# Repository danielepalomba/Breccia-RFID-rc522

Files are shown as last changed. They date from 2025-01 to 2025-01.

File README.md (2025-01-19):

# Breccia-RFID-rc522

## Required Components
- Arduino board
- rc522 RFID module
- 1 or + MIFARE 1K Keys
- Relay module
- Active buzzer

*If you do not use a relay module, take care to include a diode and transistor in your circuit to prevent eddy currents from damaging the arduino board. In case you use a relay on a pre-fabricated board, then you will have no prob .*

## Connection diagram 

| RIFD | Arduino |
| ---- |---|
| SDA  | D10 |
| SCK  | D13 |
| MOSI | D11 |
| MISO | D12 |
| GND  | GND |
| RST  | D9 |
| VCC  | 3.3V |

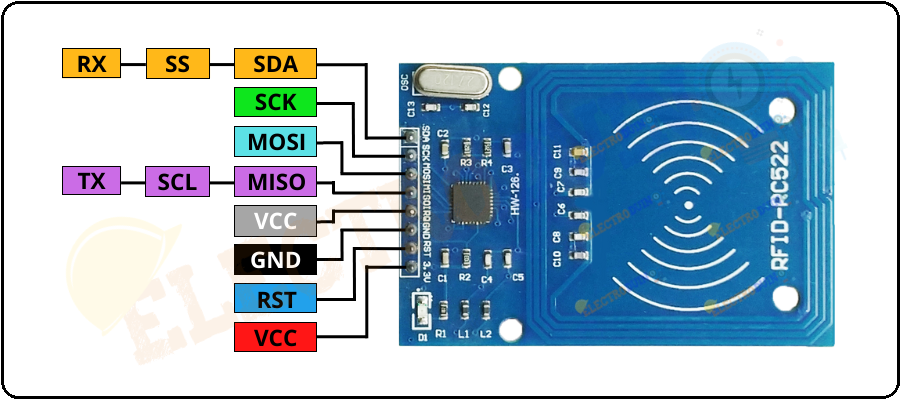
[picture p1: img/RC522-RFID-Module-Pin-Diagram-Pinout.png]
Connection diagram


| Relay board | Arduino |
| --- |:--- |
| Signal | D4 |
| VCC | 5V |
| GND | GND |

| A. Buzzer | Arduino |
|:--- | --- |
| VCC (+) | D3 |
| GND | GND |

The rc522 module communicates with the arduino via SPI protocol. Make sure you use the correct pins for your board, in my case, a UNO R3, the pins set up for the SPI protocol are:

- D10(CS),
- D11(MOSI)
- D12(MISO)
- D13(SCK) 

**Searching online you might come across the terms, COPI & CIPO. Don't worry, they correspond to (deprecated) MOSI & MISO.**

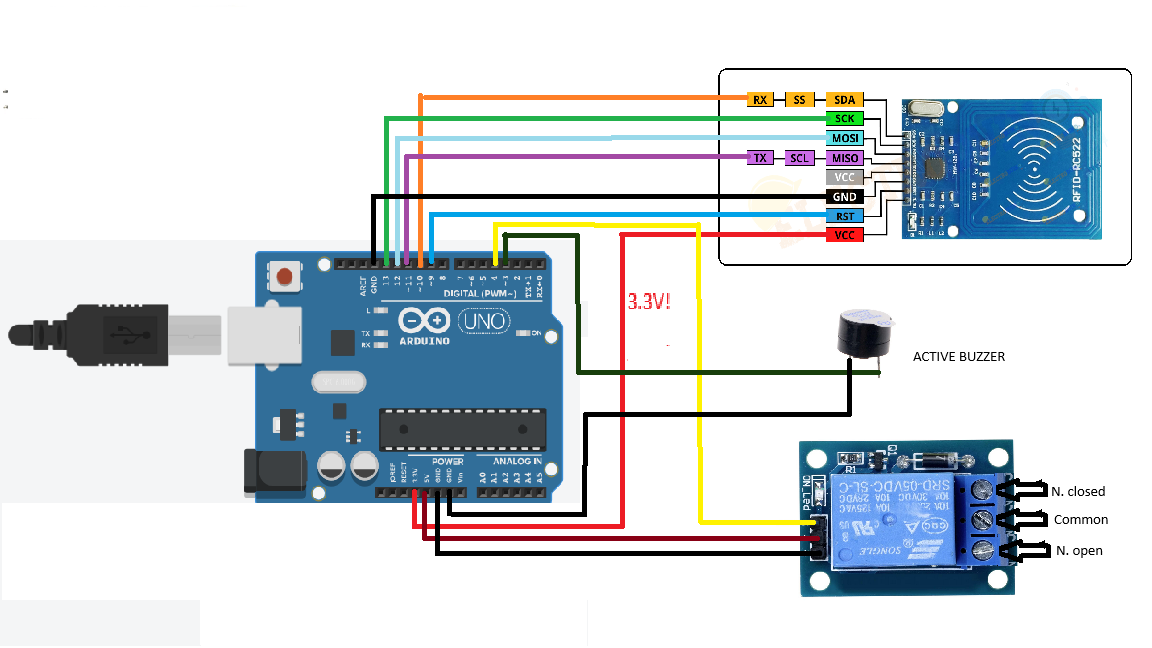
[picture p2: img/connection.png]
Connection diagram


The project also includes .stl files to print the boxes that will contain the Arduino and the RFID module. 

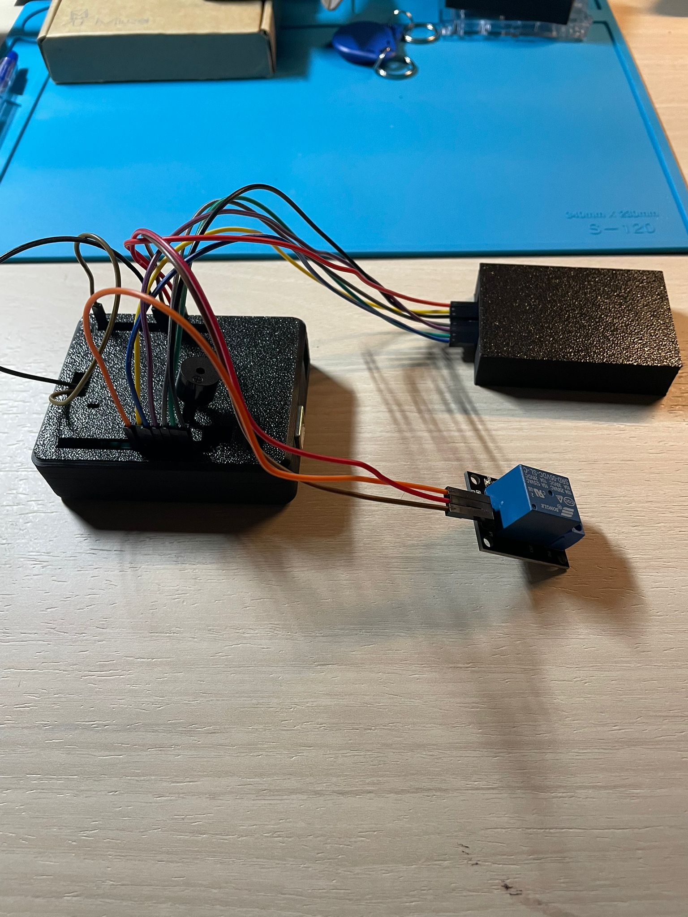
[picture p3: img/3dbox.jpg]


## About MIFARE Classic 1K
The rc522 module is usually used to read MIFARE Classic 1K cards, among the most common ones. We understand more about how they work and how we can write and read data from these cards to further customise our model.
These cards have a 1024-byte EEPROM memory, organised in 16 sectors (in the code we save the name of the key owner in sector 4). The last block in each sector is the *Sector trailer*, which contains the authentication keys and access permissions.
The operating frequency of these keys is 13.56 MHz, the standard. They use the ISO/IEC 14443-A protocol, which enables fast and secure communications.
These keys support a key authentication system (A and B). We will use only key A.

## Security-related aspects

Changing the default key “FFFFFFFFFF” is the critical first step in securing our system. Otherwise, anyone could access the data on the card.

It is important to point out that MIFARE 1K cards use Crypto-1 encryption technology, which is considered **weak**. Therefore, our system will be inherently weak. However, we can implement security measures to make it somewhat more reliable.

We specifically will implement:
- Custom security key A
- Disable security key B
- Adding an **encrypted unique code** in addition to just the uid of the RFID card.

Below is the function to be able to change the default key A

```cpp
/**
 * @param oldKey Current key
 * @param newKey New key
 * @return true if all changes were successful, false otherwise
 */
bool changeKeysForAllSectors(MFRC522::MIFARE_Key &oldKey, MFRC522::MIFARE_Key &newKey) {
  for (byte sector = 0; sector < 16; sector++) {
    byte trailerBlock = sector * 4 + 3;
    byte buffer[18];

    if (mfrc522.PCD_Authenticate(MFRC522::PICC_CMD_MF_AUTH_KEY_A, trailerBlock, &oldKey, &(mfrc522.uid)) != MFRC522::STATUS_OK) {
      Serial.print("Auth failed() - sector: ");
      Serial.println(sector);
      return false;
    }

    byte size = sizeof(buffer);
    if (mfrc522.MIFARE_Read(trailerBlock, buffer, &size) != MFRC522::STATUS_OK) {
      Serial.print("Trailer block reading failed by sector: ");
      Serial.println(sector);
      return false;
    }

    for (byte i = 0; i < 6; i++) {
      buffer[i] = newKey.keyByte[i];
    }

    if (mfrc522.MIFARE_Write(trailerBlock, buffer, 16) != MFRC522::STATUS_OK) {
      Serial.print("Writing the new failed key by sector: ");
      Serial.println(sector);
      return false;
    }

    Serial.print("Key changed by sector: ");
    Serial.println(sector);
  }

  return true;
}
```

Code to disable key B for each sector

```cpp
/**
 * Disables the B key for all sectors of the board.
 * 
 * @return true if disabling is successful, false otherwise.
 */
bool disableKeyBForAllSectors() {
  for (byte sector = 0; sector < 16; sector++) {
    byte trailerBlock = sector * 4 + 3; 
    byte buffer[18];

    if (mfrc522.PCD_Authenticate(MFRC522::PICC_CMD_MF_AUTH_KEY_A, trailerBlock, &newKey, &(mfrc522.uid)) != MFRC522::STATUS_OK) {
      Serial.print("Authentication failed by sector: ");
      Serial.println(sector);
      return false;
    }

    for (byte i = 0; i < 6; i++) {
      buffer[i] = newKey.keyByte[i];     // key A
      buffer[i + 10] = 0x00; // disable key B
    }

    buffer[6] = 0xFF; // Full access to key A
    buffer[7] = 0x07; // Full access
    buffer[8] = 0x80; // Access mode for key A
    buffer[9] = 0x69; // Other access bits

    if (mfrc522.MIFARE_Write(trailerBlock, buffer, 16) != MFRC522::STATUS_OK) {
      Serial.print("Error in disabling key B by sector: ");
      Serial.println(sector);
      return false;
    }

    Serial.print("Key B disabled by sector: ");
    Serial.println(sector);
  }

  return true;
}
```

These functions are found in the *setupCard.ino* file.

## Initializing a card

To initialize our first card, we need to open the *setupCard.ino* file and set the following global variables:
- The **key A** to change the default one.
- The AES key to encrypt the unique code.
- Enter the unique code
- Enter the name of the card  

**WARNING: The AES key must be the same in both main.ino and setupCard.ino, otherwise you will not be able to decrypt the data.**  
Once the card is initialized, all you have to do is read the hash via the *main.ino* sketch and add this to the authorized list.

Once you have started the board with the main.ino code, you should see an error like this and the buzzer should sound:

auth1

All normal, now copy and paste this hash by adding it to the authorized. Reload the sketch and try the card again.

auth2

RFID is ready, now all you have to do is connect the relay to the circuit you want to control and **have fun**.

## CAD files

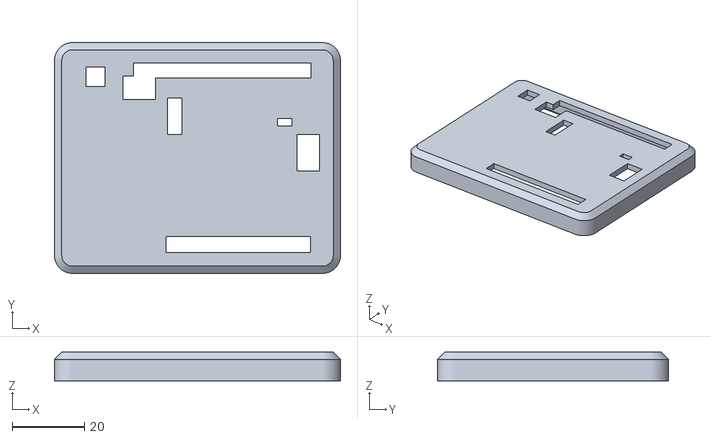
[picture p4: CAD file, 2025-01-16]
3d models/ARDUINO_UNO_BOX-Lid.stl
79.0 x 63.7 x 8.00

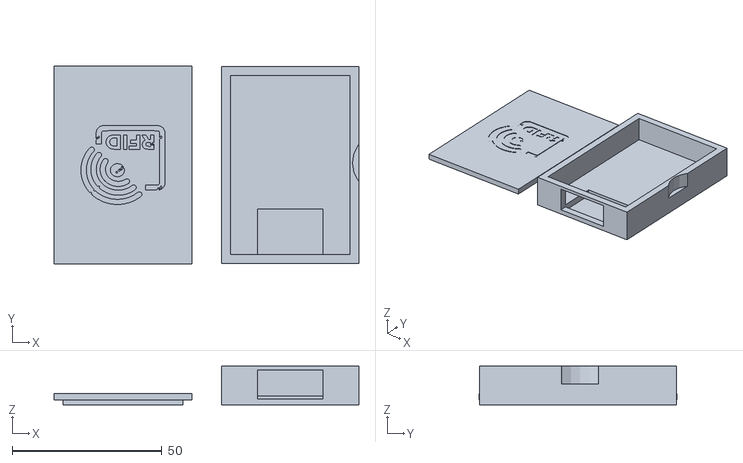
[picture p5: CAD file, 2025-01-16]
3d models/RFID Container.stl
102.0 x 66.1 x 12.9

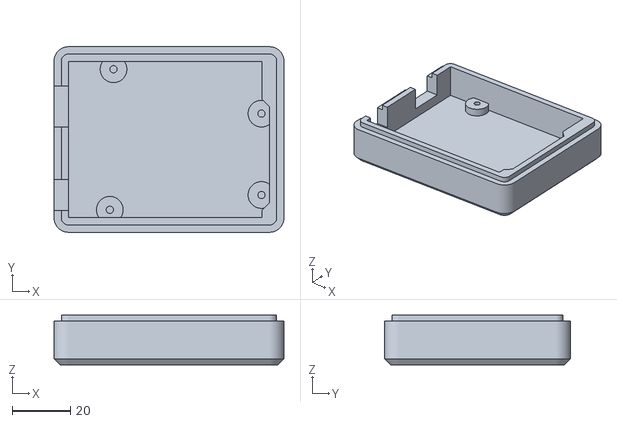
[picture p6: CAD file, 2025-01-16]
3d models/ARDUINO_UNO_BOX-Body.stl
79.0 x 63.7 x 17.0

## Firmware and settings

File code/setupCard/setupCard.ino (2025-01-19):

#include <AES.h>
#include <MFRC522.h>
#include <MFRC522Extended.h>
#include <deprecated.h>
#include <require_cpp11.h>
#include <SPI.h>

#define RST_PIN 9   
#define SS_PIN 10

//mem blocks
#define UNIQUE_ID 4
#define CARD_NAME 5

MFRC522 mfrc522(SS_PIN, RST_PIN);

//1. Setup key A
MFRC522::MIFARE_Key defaultKey = {{0xFF, 0xFF, 0xFF, 0xFF, 0xFF, 0xFF}};
MFRC522::MIFARE_Key newKey = {{0xA1, 0xB2, 0xC3, 0xD4, 0xE5, 0xF6}}; //key A

//2. Setup AES key
const byte aesKey[16] = { 0xA1, 0xB2, 0xC3, 0xD4, 0xE5, 0xF6, 0x01, 0x23,
                          0x34, 0x45, 0x56, 0x67, 0x78, 0x89, 0x9A, 0xAB };

//3. Setup the unique code
byte uniqueId[16] = "0123456789089786";

//4. Setup the name of the card
byte cardName[16] = "User";

/*After everything is set up, you can load the sketch onto your board and follow 
the instructions that are shown to you on the serial port.
Remember not to remove the card from the reader immediately, but to keep it until you are asked.
*/

AES128 aes;

void setup() {
  Serial.begin(9600);
  SPI.begin();          
  mfrc522.PCD_Init();  

  Serial.println("RFID...Do not remove the card until you are told!");
}

void loop() {
  if (!mfrc522.PICC_IsNewCardPresent() || !mfrc522.PICC_ReadCardSerial()) {
    return;
  }

  Serial.println("Card detected!");

  if (changeKeysForAllSectors(defaultKey, newKey)) {
    Serial.println("All sectors done!");
  } else {
    Serial.println("changeKeysForAllSectors() error");
  }

    if (disableKeyBForAllSectors()) {
    Serial.println("Key B disabled for all sectors!");
  } else {
    Serial.println("Error in disabling key B.");
  }

  byte encryptedUniqueId[16];
  encryptData(uniqueId, encryptedUniqueId);
  writeBlock(UNIQUE_ID, encryptedUniqueId); 
  writeBlock(CARD_NAME, cardName);

  Serial.println("You can now remove the card");
  mfrc522.PICC_HaltA();     
  mfrc522.PCD_StopCrypto1(); 
}

/**
 * @param oldKey Current key
 * @param newKey New key
 * @return true if all changes were successful, false otherwise
 */
bool changeKeysForAllSectors(MFRC522::MIFARE_Key &oldKey, MFRC522::MIFARE_Key &newKey) {
  for (byte sector = 0; sector < 16; sector++) {
    byte trailerBlock = sector * 4 + 3;
    byte buffer[18];

    if (mfrc522.PCD_Authenticate(MFRC522::PICC_CMD_MF_AUTH_KEY_A, trailerBlock, &oldKey, &(mfrc522.uid)) != MFRC522::STATUS_OK) {
      Serial.print("Auth failed() - sector: ");
      Serial.println(sector);
      return false;
    }

    byte size = sizeof(buffer);
    if (mfrc522.MIFARE_Read(trailerBlock, buffer, &size) != MFRC522::STATUS_OK) {
      Serial.print("Trailer block reading failed by sector: ");
      Serial.println(sector);
      return false;
    }

    for (byte i = 0; i < 6; i++) {
      buffer[i] = newKey.keyByte[i];
    }

    if (mfrc522.MIFARE_Write(trailerBlock, buffer, 16) != MFRC522::STATUS_OK) {
      Serial.print("Writing the new failed key by sector: ");
      Serial.println(sector);
      return false;
    }

    Serial.print("Key changed by sector: ");
    Serial.println(sector);
  }

  return true;
}

/**
 * Disables the B key for all sectors of the board.
 * 
 * @return true if disabling is successful, false otherwise.
 */
bool disableKeyBForAllSectors() {
  for (byte sector = 0; sector < 16; sector++) {
    byte trailerBlock = sector * 4 + 3; 
    byte buffer[18];

    if (mfrc522.PCD_Authenticate(MFRC522::PICC_CMD_MF_AUTH_KEY_A, trailerBlock, &newKey, &(mfrc522.uid)) != MFRC522::STATUS_OK) {
      Serial.print("Authentication failed by sector: ");
      Serial.println(sector);
      return false;
    }

    for (byte i = 0; i < 6; i++) {
      buffer[i] = newKey.keyByte[i];     // key A
      buffer[i + 10] = 0x00; // disable key B
    }

    buffer[6] = 0xFF; // Full access to key A
    buffer[7] = 0x07; // Full access
    buffer[8] = 0x80; // Access mode for key A
    buffer[9] = 0x69; // Other access bits

    if (mfrc522.MIFARE_Write(trailerBlock, buffer, 16) != MFRC522::STATUS_OK) {
      Serial.print("Error in disabling key B by sector: ");
      Serial.println(sector);
      return false;
    }

    Serial.print("Key B disabled by sector: ");
    Serial.println(sector);
  }

  return true;
}

/**
 * @param blockAddr memory block to write
 * @param message msg to save
 * @return returns true if the writing is ok, false otherwise
 */
bool writeBlock(byte blockAddr, const char* message) {
  MFRC522::StatusCode status = mfrc522.PCD_Authenticate(MFRC522::PICC_CMD_MF_AUTH_KEY_A,blockAddr,&newKey,&(mfrc522.uid));
  if (status == MFRC522::STATUS_OK) {
    //max 16 byte
    byte dataBlock[16];
    memset(dataBlock, 0, sizeof(dataBlock));
    strncpy((char*)dataBlock, message, 16);

    MFRC522::StatusCode writeStatus = mfrc522.MIFARE_Write(blockAddr, dataBlock, 16);
    if (writeStatus != MFRC522::STATUS_OK) {
      Serial.print("Write failed(): ");
      Serial.println(mfrc522.GetStatusCodeName(writeStatus));
      return false;
    }

    Serial.println("Write() ok");
    return true;
  }else{
    Serial.println("Write() failed");
  }
  return false;
}

/**
* @param plainText string in plain text
* @param cipherText encrypted string
*/
void encryptData(const byte* plainText, byte* cipherText) {
  aes.setKey(aesKey, 16);
  aes.encryptBlock(cipherText, plainText);
}

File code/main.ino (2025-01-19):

#include <SHA256.h>
#include <AES.h>
#include <MFRC522.h>
#include <MFRC522Extended.h>
#include <deprecated.h>
#include <require_cpp11.h>
#include <SPI.h>

#define RST_PIN 9   // RST RC522
#define SS_PIN 10   // SDA
#define RELAY_PIN 8
#define BUZZER_PIN A5

MFRC522 rfid(SS_PIN, RST_PIN);

//KEY A
MFRC522::MIFARE_Key key = {{0xA1, 0xB2, 0xC3, 0xD4, 0xE5, 0xF6}};

//AES KEY (you should change this for more security!)
const byte aesKey[16] = { 0xA1, 0xB2, 0xC3, 0xD4, 0xE5, 0xF6, 0x01, 0x23,
                          0x34, 0x45, 0x56, 0x67, 0x78, 0x89, 0x9A, 0xAB };
AES128 aes;

//Auth hash storage (enter the hash you get by running the card setup)
String authorizedHashes[] = {
  "8642966f0d60111ffa9009f8f17b79b3f130636190cf0c432b65b4e18037160b"
};
int hashListSize = sizeof(authorizedHashes) / sizeof(String);

void setup() {
  pinMode(RELAY_PIN, OUTPUT);
  pinMode(BUZZER_PIN, OUTPUT);
  Serial.begin(9600);
  SPI.begin();
  rfid.PCD_Init();
  Serial.println("Waiting...");
}

void loop() {
  if (!rfid.PICC_IsNewCardPresent() || !rfid.PICC_ReadCardSerial()) {
    return;
  }

  Serial.println("Card detected");

  //Read and decrypt uniqueId
  String uniqueCode = readBlock(4);
  byte decryptedUniqueId[16];
  decryptData(uniqueCode.c_str(), decryptedUniqueId);

  Serial.print("User: ");
  Serial.println(readBlock(5));

  //Read the UID of the card 
  String uid = getUID();

  String hashedUID = createHash(uid + (char*)decryptedUniqueId);
  Serial.println(hashedUID);
  
  if(checkHash(hashedUID)){
    Serial.print("Authorized");
    fireRele();
  }else{
    Serial.println("WARNING: Unknown card readed!");
    fireBuzzer(6000);
  }

  rfid.PICC_HaltA();
  rfid.PCD_StopCrypto1();
  delay(5000);
}

/**
* @return a string containing the uid of the read card
*/
String getUID() {
  String uid = "";
  for (int i = 0; i < rfid.uid.size; i++) {
    uid += rfid.uid.uidByte[i] < 0x10 ? "0" : "";
    uid += String(rfid.uid.uidByte[i], HEX);
  }
  rfid.PICC_HaltA();
  return uid;
}

/**
* @param data string of which to create the hash
* @return the hash in string form of the string taken as input
*/
String createHash(String data) {
  SHA256 sha256;
  byte hash[32]; // SHA-256 output 32 byte
  sha256.update((const byte*)data.c_str(), data.length());
  sha256.finalize(hash, sizeof(hash));

  String hashString = "";
  for (int i = 0; i < 32; i++) {
    if (hash[i] < 0x10) {
      hashString += "0";
    }
    hashString += String(hash[i], HEX);
  }
  return hashString;
}

/**
* @param hash to compare with authorized hashes 
* @return true if the hash is authorized, false otherwise
*/
bool checkHash(String hash) {
  for (int i = 0; i < hashListSize; i++) {
    if (authorizedHashes[i] == hash) {
      return true;
    }
  }
  return false;
}

/**
* @param blockAddr memory block to read
* @return string containing the data read
*/
String readBlock(byte blockAddr) {
  if (authenticate(blockAddr)) {
    byte buffer[18];
    byte size = sizeof(buffer);

    MFRC522::StatusCode status = rfid.MIFARE_Read(blockAddr, buffer, &size);
    if (status != MFRC522::STATUS_OK) {
      Serial.print("Read() failed: ");
      Serial.println(rfid.GetStatusCodeName(status));
      return "";
    }

/* DEBUG ONLY
    Serial.print("Data ");
    Serial.print(blockAddr);
    Serial.print(": ");

    for (byte i = 0; i < 16; i++) {
      Serial.print(buffer[i], HEX);
      Serial.print(" ");
    }
    Serial.println();
*/
    // Create the string
    char message[17];
    memcpy(message, buffer, 16);
    message[16] = '\0';

    return message;
  }
  return "";
}

/**
* @param blockAddr memory block to be authenticated in order to access it 
* @return true if authentication goes well, false otherwise
*/
bool authenticate(byte blockAddr) {
  MFRC522::StatusCode status = rfid.PCD_Authenticate(
    MFRC522::PICC_CMD_MF_AUTH_KEY_A,
    blockAddr,
    &key,
    &(rfid.uid)
  );

  if (status != MFRC522::STATUS_OK) {
    Serial.print("Auth failed: ");
    Serial.println(rfid.GetStatusCodeName(status));
    return false;
  }
  return true;
}

void fireRele(){
  digitalWrite(RELAY_PIN, HIGH);
  delay(1000);
  digitalWrite(RELAY_PIN, LOW);
}

/**
 @param dur duration of activation
*/
void fireBuzzer(unsigned long dur) {
  unsigned long init = millis();
  while (millis() - init < dur) {
    digitalWrite(BUZZER_PIN, HIGH);
    delay(100);
    digitalWrite(BUZZER_PIN, LOW);
    delay(100);
  }
}

/**
* @param cipherText text to decrypt 
* @param plainText plaintext restored to output
*/
void decryptData(const byte* cipherText, byte* plainText) {
  aes.setKey(aesKey, 16);
  aes.decryptBlock(plainText, cipherText);

  plainText[16] = '\0'; 
}
